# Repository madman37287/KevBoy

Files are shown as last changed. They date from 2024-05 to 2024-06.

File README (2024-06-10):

What is the KevBoy?

In its current state, the KevBoy is a breadboard prototype of a handheld RPI based retro gaming system using the retropie image.
ADD IMAGE

The KevBoy is a 

What is the purpose of making this public git repository?

1. Back-up data.  This project already had to be re-designed from scratch once in the past due to a laptop harddrive failure.  
2. Some SW and HW lack a large number of examples or documentation on the web. I hope this repository and documentation can assist with someone else's learning.
3. Method of showing off the project to any interested parties.

What has already been implemented within the KevBoy?

As previously mentioned, the KevBoy currently has a breadboard prototype shown in the image below.
ADD IMAGE

The breadboard design has 3 visible layers to it.  In the bottom layer, we have the controls.
These controls match what you would expect from a standard controller:
* D-Pad on the far left
* A, B, X, Y buttons on the far right
* Two analog sticks
* select (left) and start (right) buttons in between the analog sticks.

INSERT DIAGRAM

There is also an MCP3008 ADC between the analog sticks that convert the analog voltage outputted from the x and y axis potentiometers into a digital code readable by the PI.

The layer above the controls lives the necessary electrical components needed to connect the controls to the GPIO pins.  
In this layer we have LEDs acting only as Diodes.  These diodes are necessary due to the button matrix solution used to reduce the number of GPIO pins used from 16 to 8.
Without the diodes, multiple button presses can lead to an unpressed button being incorrectly registered (see below)

INSERT DIAGRAM

In its current prototype state, the PI currently has 11 connected buttons (including L3 on the DS3 analog), while the final will support at least 16 when adding R3 and the Triggers.
With several other devices needing to be connected to the GPIO pins, such as ADC, PWM speakers, UPS UART connections, ect, there are simply not enough pins.
The HW/SW solution was to build a button matrix, in which 16 buttons could be supported with 8 pins.

What still needs to be implemented?

* Upgrade to RPI5 (expecting CM5 to release later this year. CM4 to CM5 will not require PCB changes)
* Battery solution for RPI5 (5V 5A max compared to RPI4 5V 3A)
* PCB updates & PCB prototype
* 3D printable model for casing
* digitally controllable potentiometers for volume control
* code to support WIFI and Bluetooth status display. Perhaps also an airplane mode.
* Unit cooling

Setup:

Sound:
https://learn.adafruit.com/adafruit-max98357-i2s-class-d-mono-amp/raspberry-pi-usage

Background music: 
https://github.com/Naprosnia/RetroPie_BGM_Player

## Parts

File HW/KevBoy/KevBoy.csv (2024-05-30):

Source: | C:\Users\kevin\OneDrive\Documents\Kevboy\Kevboy.kicad_sch
Date: | 8/27/2022 11:19:42 AM
Tool: | Eeschema (5.99.0-12724-g8c8d66a181)
Generator: | C:\Program Files\KiCad\5.99\bin\scripting\plugins/bom_csv_grouped_by_value.py
Component Count: | 47
Individual Components:
Item | Qty | Reference(s) | Value | LibPart | Footprint | Datasheet | Description | Height | Manufacturer_Name | Manufacturer_Part_Number | Mouser Part Number | Mouser Price/Stock
 |  | D1 | DIODE | pspice:DIODE | Diode_SMD:D_0805_2012Metric | ~
 |  | D2 | DIODE | pspice:DIODE | Diode_SMD:D_0805_2012Metric | ~
 |  | D3 | DIODE | pspice:DIODE | Diode_SMD:D_0805_2012Metric | ~
 |  | D4 | DIODE | pspice:DIODE | Diode_SMD:D_0805_2012Metric | ~
 |  | D5 | DIODE | pspice:DIODE | Diode_SMD:D_0805_2012Metric | ~
 |  | D6 | DIODE | pspice:DIODE | Diode_SMD:D_0805_2012Metric | ~
 |  | D7 | DIODE | pspice:DIODE | Diode_SMD:D_0805_2012Metric | ~
 |  | D8 | DIODE | pspice:DIODE | Diode_SMD:D_0805_2012Metric | ~
 |  | D9 | DIODE | pspice:DIODE | Diode_SMD:D_0805_2012Metric | ~
 |  | D10 | DIODE | pspice:DIODE | Diode_SMD:D_0805_2012Metric | ~
 |  | D11 | DIODE | pspice:DIODE | Diode_SMD:D_0805_2012Metric | ~
 |  | D12 | DIODE | pspice:DIODE | Diode_SMD:D_0805_2012Metric | ~
 |  | J5 | 208658-1051 | mouser:208658-1051 | 2086581051 | https://www.mouser.com/ProductDetail/Molex/208658-1051?qs=BJlw7L4Cy7%252Bu27sIkZU3Xw%3D%3D | 1.0 HDMI R/A HEADER ASSY (I/M TYPE) | 6.44 | Molex | 208658-1051 | 538-208658-1051 | https://www.mouser.co.uk/ProductDetail/Molex/208658-1051?qs=BJlw7L4Cy7%252Bu27sIkZU3Xw%3D%3D
 |  | J6 | 208658-1051 | mouser:208658-1051 | 2086581051 | https://www.mouser.com/ProductDetail/Molex/208658-1051?qs=BJlw7L4Cy7%252Bu27sIkZU3Xw%3D%3D | 1.0 HDMI R/A HEADER ASSY (I/M TYPE) | 6.44 | Molex | 208658-1051 | 538-208658-1051 | https://www.mouser.co.uk/ProductDetail/Molex/208658-1051?qs=BJlw7L4Cy7%252Bu27sIkZU3Xw%3D%3D
 |  | J7 | 692122030100 | mouser:692122030100 | 692122030100 | https://katalog.we-online.de/em/datasheet/692122030100.pdf | Wurth Elektronik WR-COM Series, Right Angle Through Hole, Version 3.0 Type A USB Connector, Receptacle | 7.55 | Wurth Elektronik | 692122030100 | 710-692122030100 | https://www.mouser.co.uk/ProductDetail/Wurth-Elektronik/692122030100?qs=e5m3IbTHPW%252BwkSEzX%252BzXuw%3D%3D
 |  | J8 | 692122030100 | mouser:692122030100 | 692122030100 | https://katalog.we-online.de/em/datasheet/692122030100.pdf | Wurth Elektronik WR-COM Series, Right Angle Through Hole, Version 3.0 Type A USB Connector, Receptacle | 7.55 | Wurth Elektronik | 692122030100 | 710-692122030100 | https://www.mouser.co.uk/ProductDetail/Wurth-Elektronik/692122030100?qs=e5m3IbTHPW%252BwkSEzX%252BzXuw%3D%3D
 |  | J9 | 692122030100 | mouser:692122030100 | 692122030100 | https://katalog.we-online.de/em/datasheet/692122030100.pdf | Wurth Elektronik WR-COM Series, Right Angle Through Hole, Version 3.0 Type A USB Connector, Receptacle | 7.55 | Wurth Elektronik | 692122030100 | 710-692122030100 | https://www.mouser.co.uk/ProductDetail/Wurth-Elektronik/692122030100?qs=e5m3IbTHPW%252BwkSEzX%252BzXuw%3D%3D
 |  | J10 | 692122030100 | mouser:692122030100 | 692122030100 | https://katalog.we-online.de/em/datasheet/692122030100.pdf | Wurth Elektronik WR-COM Series, Right Angle Through Hole, Version 3.0 Type A USB Connector, Receptacle | 7.55 | Wurth Elektronik | 692122030100 | 710-692122030100 | https://www.mouser.co.uk/ProductDetail/Wurth-Elektronik/692122030100?qs=e5m3IbTHPW%252BwkSEzX%252BzXuw%3D%3D
 |  | J11 | USB4110-GF-A | mouser:USB4110-GF-A | USB4110GFA | https://gct.co/files/drawings/usb4110.pdf | CONN USB 2.0 TYPE-C R/A SMT | 3.26 | GCT (GLOBAL CONNECTOR TECHNOLOGY) | USB4110-GF-A | 640-USB4110-GF-A | https://www.mouser.co.uk/ProductDetail/GCT/USB4110-GF-A?qs=KUoIvG%2F9IlYiZvIXQjyJeA%3D%3D
 |  | J12 | MEM2051-00-195-00-A | mouser:MEM2051-00-195-00-A | MEM20510019500A | https://gct.co/files/drawings/mem2051.pdf | MICRO SD PUSH PUSH, OPEN, SMT, 1 | 2.05 | GCT (GLOBAL CONNECTOR TECHNOLOGY) | MEM2051-00-195-00-A | 640-MEM20510019500A | https://www.mouser.co.uk/ProductDetail/GCT/MEM2051-00-195-00-A?qs=KUoIvG%2F9Ilat7yfJRNWXUQ%3D%3D
 |  | J13 | Conn_01x03 | Connector_Generic:Conn_01x03 | Connector_JST:JST_EH_S3B-EH_1x03_P2.50mm_Horizontal | ~
 |  | J14 | Conn_01x04 | Connector_Generic:Conn_01x04 | Connector_JST:JST_EH_S4B-EH_1x04_P2.50mm_Horizontal | ~
 |  | J15 | Conn_01x04 | Connector_Generic:Conn_01x04 | Connector_JST:JST_EH_S4B-EH_1x04_P2.50mm_Horizontal | ~
 |  | R1 | 470 | Device:R | Resistor_SMD:R_1206_3216Metric | ~
 |  | R2 | 470 | Device:R | Resistor_SMD:R_1206_3216Metric | ~
 |  | R3 | 470 | Device:R | Resistor_SMD:R_1206_3216Metric | ~
 |  | R4 | 470 | Device:R | Resistor_SMD:R_1206_3216Metric | ~
 |  | R5 | 10k | Device:R | Resistor_SMD:R_1206_3216Metric | ~
 |  | R6 | 10k | Device:R | Resistor_SMD:R_1206_3216Metric | ~
 |  | R7 | 10k | Device:R | Resistor_SMD:R_1206_3216Metric | ~
 |  | SW1 | SW_Push | Switch:SW_Push | Button_Switch_THT:SW_PUSH_6mm_H7.3mm | ~
 |  | SW2 | SW_Push | Switch:SW_Push | Button_Switch_THT:SW_PUSH_6mm_H7.3mm | ~
 |  | SW3 | SW_Push | Switch:SW_Push | Button_Switch_THT:SW_PUSH_6mm_H7.3mm | ~
 |  | SW4 | SW_Push | Switch:SW_Push | Button_Switch_THT:SW_PUSH_6mm_H7.3mm | ~
 |  | SW5 | SW_Push | Switch:SW_Push | Button_Switch_THT:SW_PUSH_6mm_H7.3mm | ~
 |  | SW6 | SW_Push | Switch:SW_Push | Button_Switch_THT:SW_PUSH_6mm_H7.3mm | ~
 |  | SW7 | SW_Push | Switch:SW_Push | Button_Switch_THT:SW_PUSH_6mm_H7.3mm | ~
 |  | SW8 | SW_Push | Switch:SW_Push | Button_Switch_THT:SW_PUSH_6mm_H7.3mm | ~
 |  | SW9 | SW_Push | Switch:SW_Push | Button_Switch_THT:SW_PUSH_6mm_H7.3mm | ~
 |  | SW10 | SW_Push | Switch:SW_Push | Button_Switch_THT:SW_PUSH_6mm_H7.3mm | ~
 |  | SW11 | SW_Push | Switch:SW_Push | Button_Switch_THT:SW_PUSH_6mm_H7.3mm | ~
 |  | SW12 | SW_Push | Switch:SW_Push | Button_Switch_THT:SW_PUSH_6mm_H7.3mm | ~
 |  | U1 | Conn_01x40_Male | Connector:Conn_01x40_Male |  | ~
 |  | U2 | MCP3008 | Analog_ADC:MCP3008 | MCP3008:SOIC127P600X175-16N | http://ww1.microchip.com/downloads/en/DeviceDoc/21295d.pdf
 |  | U3 | cm4conn | cm4conn:cm4conn | CM4IO:Raspberry-Pi-4-Compute-Module
 |  | U4 | DS3_Analog | :DS3_Analog_1 | joystick:JOYSTICK
 |  | U5 | DS3_Analog | AnalogStick:DS3_Analog | joystick:JOYSTICK
Collated Components:
Item | Qty | Reference(s) | Value | LibPart | Footprint | Datasheet | Description | Height | Manufacturer_Name | Manufacturer_Part_Number | Mouser Part Number | Mouser Price/Stock
1 | 12 | D1, D2, D3, D4, D5, D6, D7, D8, D9, D10, D11, D12 | DIODE | pspice:DIODE | Diode_SMD:D_0805_2012Metric | ~
2 | 2 | J5, J6 | 208658-1051 | mouser:208658-1051 | 2086581051 | https://www.mouser.com/ProductDetail/Molex/208658-1051?qs=BJlw7L4Cy7%252Bu27sIkZU3Xw%3D%3D | 1.0 HDMI R/A HEADER ASSY (I/M TYPE) | 6.44 | Molex | 208658-1051 | 538-208658-1051 | https://www.mouser.co.uk/ProductDetail/Molex/208658-1051?qs=BJlw7L4Cy7%252Bu27sIkZU3Xw%3D%3D
3 | 4 | J7, J8, J9, J10 | 692122030100 | mouser:692122030100 | 692122030100 | https://katalog.we-online.de/em/datasheet/692122030100.pdf | Wurth Elektronik WR-COM Series, Right Angle Through Hole, Version 3.0 Type A USB Connector, Receptacle | 7.55 | Wurth Elektronik | 692122030100 | 710-692122030100 | https://www.mouser.co.uk/ProductDetail/Wurth-Elektronik/692122030100?qs=e5m3IbTHPW%252BwkSEzX%252BzXuw%3D%3D
4 | 1 | J11 | USB4110-GF-A | mouser:USB4110-GF-A | USB4110GFA | https://gct.co/files/drawings/usb4110.pdf | CONN USB 2.0 TYPE-C R/A SMT | 3.26 | GCT (GLOBAL CONNECTOR TECHNOLOGY) | USB4110-GF-A | 640-USB4110-GF-A | https://www.mouser.co.uk/ProductDetail/GCT/USB4110-GF-A?qs=KUoIvG%2F9IlYiZvIXQjyJeA%3D%3D
5 | 1 | J12 | MEM2051-00-195-00-A | mouser:MEM2051-00-195-00-A | MEM20510019500A | https://gct.co/files/drawings/mem2051.pdf | MICRO SD PUSH PUSH, OPEN, SMT, 1 | 2.05 | GCT (GLOBAL CONNECTOR TECHNOLOGY) | MEM2051-00-195-00-A | 640-MEM20510019500A | https://www.mouser.co.uk/ProductDetail/GCT/MEM2051-00-195-00-A?qs=KUoIvG%2F9Ilat7yfJRNWXUQ%3D%3D
6 | 1 | J13 | Conn_01x03 | Connector_Generic:Conn_01x03 | Connector_JST:JST_EH_S3B-EH_1x03_P2.50mm_Horizontal | ~
7 | 2 | J14, J15 | Conn_01x04 | Connector_Generic:Conn_01x04 | Connector_JST:JST_EH_S4B-EH_1x04_P2.50mm_Horizontal | ~
8 | 4 | R1, R2, R3, R4 | 470 | Device:R | Resistor_SMD:R_1206_3216Metric | ~
9 | 3 | R5, R6, R7 | 10k | Device:R | Resistor_SMD:R_1206_3216Metric | ~
10 | 12 | SW1, SW2, SW3, SW4, SW5, SW6, SW7, SW8, SW9, SW10, SW11, SW12 | SW_Push | Switch:SW_Push | Button_Switch_THT:SW_PUSH_6mm_H7.3mm | ~
11 | 1 | U1 | Conn_01x40_Male | Connector:Conn_01x40_Male |  | ~
12 | 1 | U2 | MCP3008 | Analog_ADC:MCP3008 | MCP3008:SOIC127P600X175-16N | http://ww1.microchip.com/downloads/en/DeviceDoc/21295d.pdf
13 | 1 | U3 | cm4conn | cm4conn:cm4conn | CM4IO:Raspberry-Pi-4-Compute-Module
14 | 1 | U4 | DS3_Analog | :DS3_Analog_1 | joystick:JOYSTICK
15 | 1 | U5 | DS3_Analog | AnalogStick:DS3_Analog | joystick:JOYSTICK

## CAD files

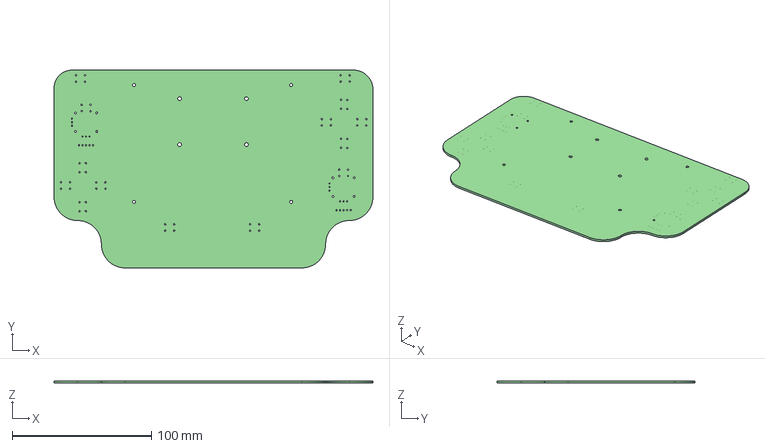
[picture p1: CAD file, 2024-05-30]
HW/KevBoy/KevBoy.step
229.0 x 142.0 x 1.60 mm

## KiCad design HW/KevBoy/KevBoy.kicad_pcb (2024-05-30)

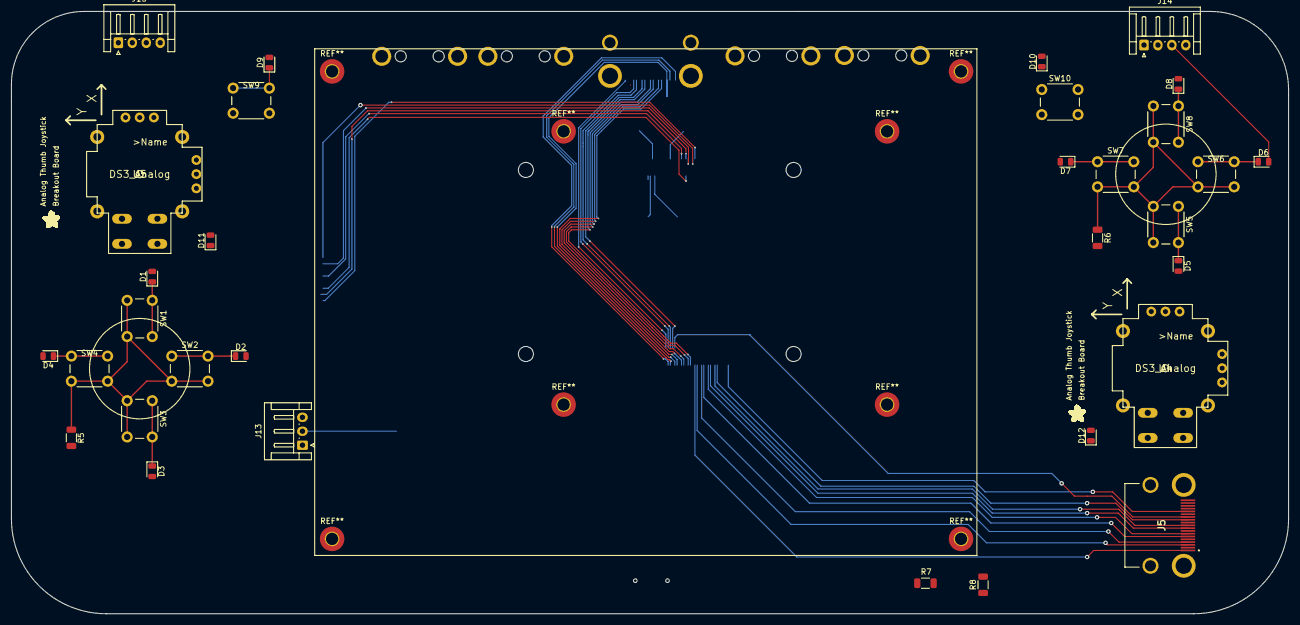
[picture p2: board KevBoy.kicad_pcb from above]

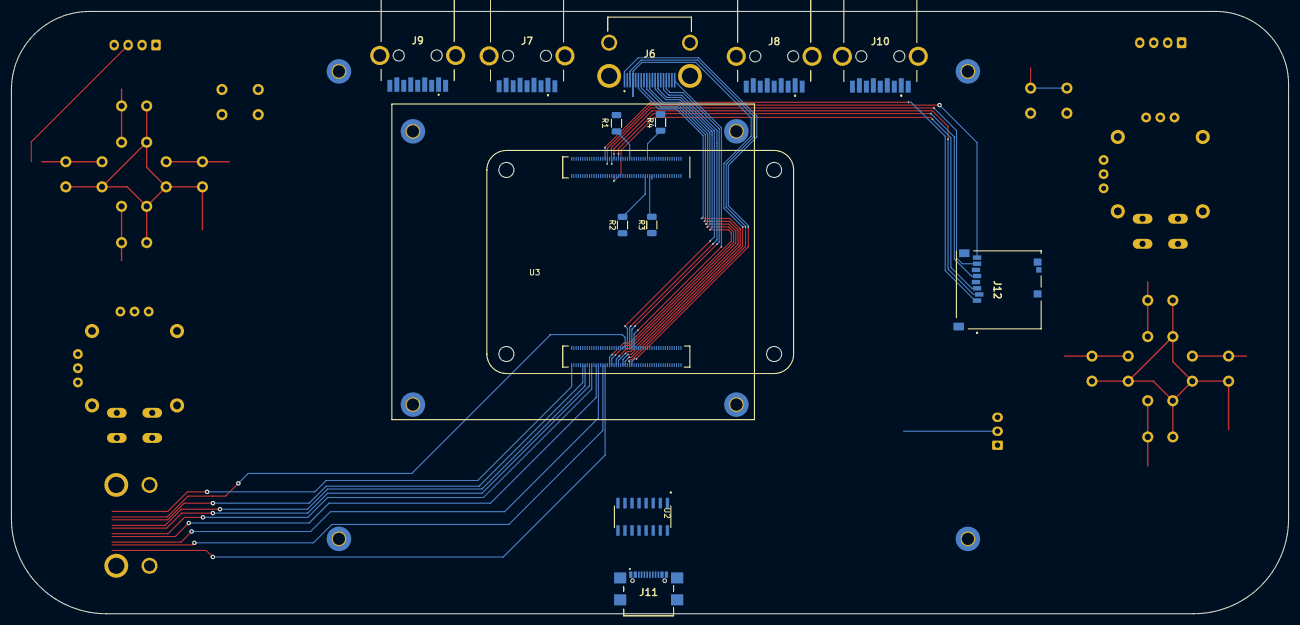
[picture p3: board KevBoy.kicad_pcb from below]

Board: 2 copper layers, 229.0 x 108.0 mm, 47 parts (13 on the bottom side), 58 nets.

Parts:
D1, D2, D3, D4, D5, D6, D7, D8, D9, D10, D11, D12: DIODE; D_0805_2012Metric
J5, J6: 208658-1051; 2086581051
J7, J8, J9, J10: 692122030100
J11: USB4110-GF-A; USB4110GFA
J12: MEM2051-00-195-00-A; MEM20510019500A
J13: Conn_01x03; JST_EH_S3B-EH_1x03_P2.50mm_Horizontal
J14, J15: Conn_01x04; JST_EH_S4B-EH_1x04_P2.50mm_Horizontal
R1, R2, R3, R4: 470; R_1206_3216Metric
R5, R6, R7, R8: 10k; R_1206_3216Metric
SW1, SW2, SW3, SW4, SW5, SW6, SW7, SW8, SW9, SW10: SW_Push; SW_PUSH_6mm_H7.3mm
U2: MCP3008; SOIC127P600X175-16N
U3: cm4conn; Raspberry-Pi-4-Compute-Module
U4, U5: DS3_Analog; JOYSTICK
U$1, U$1#2: ADAFRUIT200MIL

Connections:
5V: J13.1, U3.77, U3.79, U3.81, U3.83, U3.85, U3.87
ChargerInput: J11.A4, J11.A9, J11.B4, J11.B9
GND: J11.A1, J11.A12, J11.B1, J11.B12, J12.P6 (VSS), J13.3, R5.2, R6.2, R7.2, R8.2, U2.9 (DGND), U2.14 (AGND), U3.1, U3.2, U3.7, U3.8, U3.13, U3.14, U3.22, U3.23, U3.32, U3.33, U3.42, U3.43, U3.52, U3.53, U3.59, U3.60, U3.65, U3.66, U3.71, U3.74, U3.98, U3.107, U3.108, U3.113, U3.114, U3.119, U3.120, U3.125, U3.126, U3.131, U3.132, U3.137, U3.138, U3.144, U3.150, U3.155, U3.156, U3.161, U3.162, U3.167, U3.168, U3.173, U3.174, U3.179, U3.180, U3.185, U3.186, U3.191, U3.192, U3.197, U3.198
unnamed: D1.1 (K), SW1.1
unnamed: D1.2 (A), D5.2 (A), D9.2 (A), J14.2, R1.1
unnamed: D2.1 (K), SW2.1
unnamed: D3.1 (K), SW3.1
unnamed: D4.1 (K), SW4.1
unnamed: D5.1 (K), SW5.1
unnamed: D6.1 (K), SW6.1
unnamed: D7.1 (K), SW7.1
unnamed: D8.1 (K), SW8.1
unnamed: D9.1 (K), SW9.1
unnamed: D10.1 (K), SW10.1
unnamed: D2.2 (A), D6.2 (A), D10.2 (A), J14.3, R2.1
unnamed: D3.2 (A), D7.2 (A), D11.2 (A), J15.2, R3.1
unnamed: D4.2 (A), D8.2 (A), D12.2 (A), J15.3, R4.1
unnamed: J5.1, U3.170
unnamed: J5.3, U3.172
unnamed: J5.4, U3.176
unnamed: J5.6, U3.178
unnamed: J5.7, U3.182
unnamed: J5.9, U3.184
unnamed: J5.10, U3.188
unnamed: J5.12, U3.190
unnamed: J5.13, U3.151
unnamed: J5.15, U3.200
unnamed: J5.16, U3.199
unnamed: J5.19, U3.153
unnamed: J6.1, U3.146
unnamed: J6.3, U3.148
unnamed: J6.4, U3.152
unnamed: J6.6, U3.154
unnamed: J6.7, U3.158
unnamed: J6.9, U3.160
unnamed: J6.10, U3.164
unnamed: J6.12, U3.166
unnamed: J6.13, U3.149
unnamed: J6.15, U3.147
unnamed: J6.16, U3.145
unnamed: J6.19, U3.143
unnamed: J12.P1 (DAT2), U3.69
unnamed: J12.P2 (CD/DAT3), U3.61
unnamed: J12.P3 (CMD), U3.62
unnamed: J12.P5 (CLK), U3.57
unnamed: J12.P7 (DAT0), U3.63
unnamed: J12.P8 (DAT1), U3.67
unnamed: J13.2, U3.28
unnamed: J14.4, J15.1
unnamed: J15.4, R8.1
unnamed: R1.2, U3.47
unnamed: R2.2, U3.34
unnamed: R3.2, U3.30
unnamed: R4.2, U3.31
unnamed: R5.1, SW1.2, SW2.2, SW3.2, SW4.2, U3.50
unnamed: R6.1, SW5.2, SW6.2, SW7.2, SW8.2, U3.48
unnamed: R7.1, SW9.2, SW10.2, U3.46
unnamed: U2.15 (Vref), U2.16 (Vdd)

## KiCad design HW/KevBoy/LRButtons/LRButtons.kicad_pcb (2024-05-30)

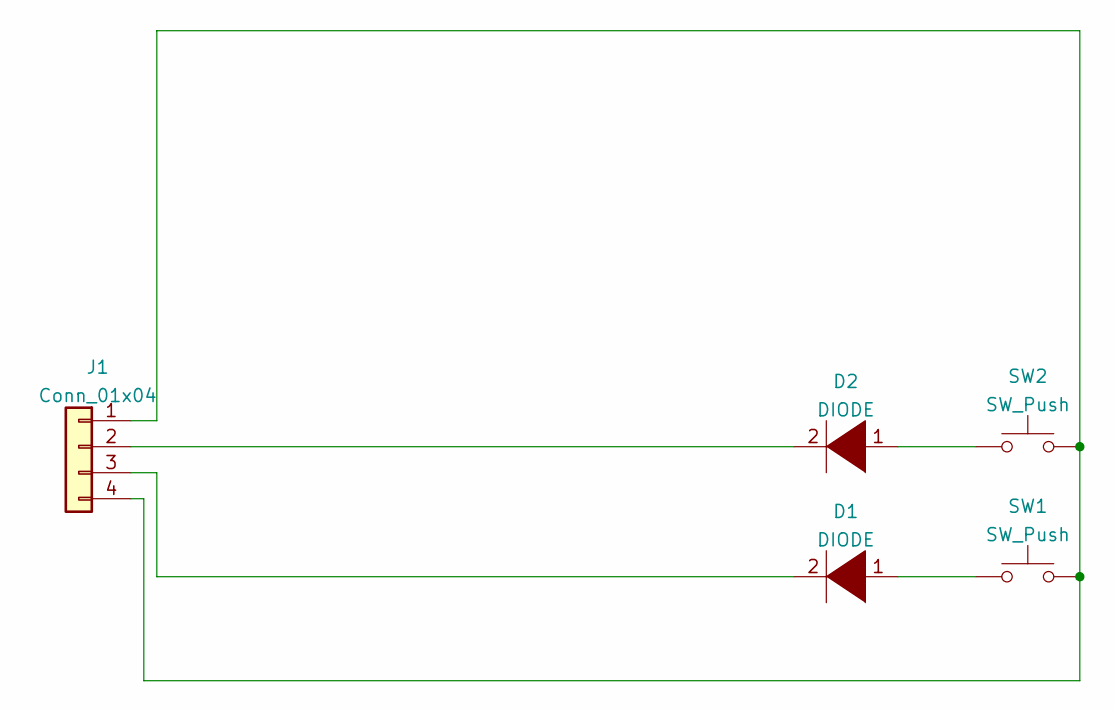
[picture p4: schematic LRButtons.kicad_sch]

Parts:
D1, D2: DIODE; D_0805_2012Metric
J1: Conn_01x04; JST_EH_B4B-EH-A_1x04_P2.50mm_Vertical
SW1, SW2: SW_Push; SW_PUSH_6mm_H7.3mm

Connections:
unnamed: D1.2 (A), J1.3
unnamed: D2.2 (A), J1.2
unnamed: J1.1, J1.4, SW1.2, SW2.2
unnamed: D1.1 (K), SW1.1
unnamed: D2.1 (K), SW2.1

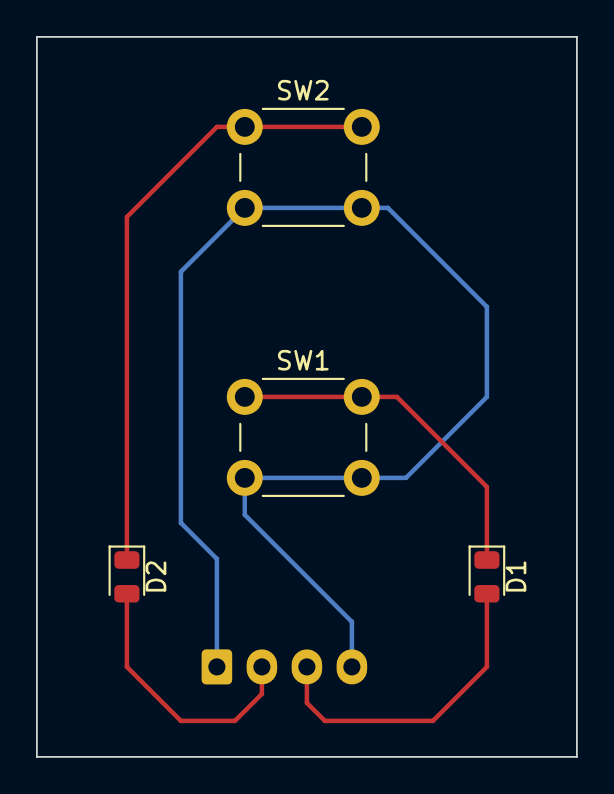
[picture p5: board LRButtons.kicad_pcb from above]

Board: 2 copper layers, 30.0 x 40.0 mm, 5 parts (1 on the bottom side), 5 nets.

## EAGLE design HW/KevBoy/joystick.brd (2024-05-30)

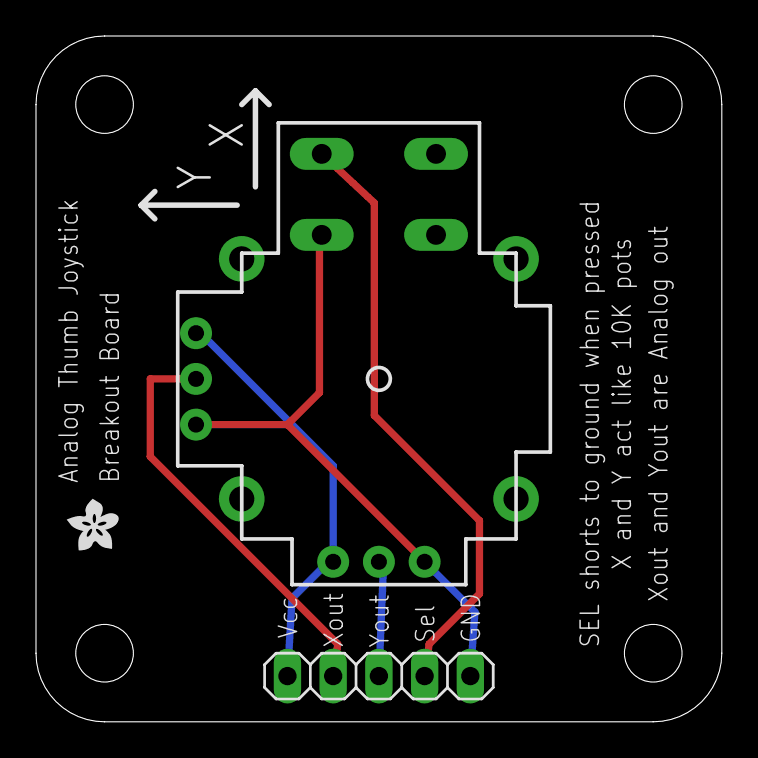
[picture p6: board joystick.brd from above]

Board: 2 copper layers, 38.1 x 38.1 mm, 3 parts (0 on the bottom side), 5 nets.

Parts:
JP1: 1X05
U1: JOYSTICKPTH; JOYSTICK
U$1: ADAFRUIT200MIL

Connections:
unnamed: JP1.5, U1.H1, U1.V1
unnamed: JP1.1, U1.B2A, U1.H3, U1.V3
unnamed: JP1.4, U1.V2
unnamed: JP1.3, U1.H2
unnamed: JP1.2, U1.B1A

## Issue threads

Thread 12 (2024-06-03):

RPi UPSPack max current investigation

madman37287, 2024-06-03:
The documentation refers to 3A max output current.  However, it is unclear if this is a constraint of the board or of the batteries themselves.  Because two LIPO batteries are being investigated anyways, two of these boards can be connected in parallel in theory, with diodes preventing reversed current.  the obvious downside is that this will double the cost of the battery solution from 33 to 66 per build.  Plus will be double battery life and potentially allow for USB support.

USBA 2.0 uses max of .5A, which means max current draw from the usb ports is 2A.  With RPi 5 potentially drawing a max of 5A, this could put us an amp over max current. More investigation necessary.

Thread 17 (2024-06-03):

Status button implementation

madman37287, 2024-06-03:
all status displays should be toggleable with a button or event.  A button will be placed on the bottom or back of the board with the express purpose of toggling the status bar.  This way, battery, wifi, ect can be checked at any given moment without fear of covering crucial parts of the screen.

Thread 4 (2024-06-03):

Replace current MicroSD card reader with the one currently being used by RPI's CM dev board

madman37287, 2024-06-03:
Although current SD Card reader should be sufficient, for the purpose of this project I want to use one that is already proven to work by RPi manufacturers.

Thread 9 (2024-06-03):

Build PCB Prototype

madman37287, 2024-06-03:
The easiest way to do this will be to use solder paste and stencil.  It is rumored that modern easy bake ovens get hot enough to flow solder paste and may be a viable option.  Heat gun may also be viable.

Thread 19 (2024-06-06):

RPi5 Compatibility: Switch to I2S audio

madman37287, 2024-06-06:
PWM audio is no longer supported on the pi5.  as such, the audio output should be switched to the I2S protocol.

madman37287, 2024-06-06:
For the time being, bluetooth speaker can be used for testing as a workaround

madman37287, 2024-06-10:
complete with instructions from: https://learn.adafruit.com/adafruit-max98357-i2s-class-d-mono-amp/raspberry-pi-usage

Closed 2024-06-10.

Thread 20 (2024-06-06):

RPi 5 Compatibility: Ensure ButtonLogic5.py script works on the RPi 4 for cross compatibility

madman37287, 2024-06-06:
Button logic script had to be altered due to a change in the GPIO interface in the RPi5.  However, because gpiozero is compatible with all raspberry pi models, it should be cross compatible as well.  Cross compatibility is important because the first PCB model will be built with a CM4 due to the CM5 not existing yet.

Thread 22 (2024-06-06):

RPi 5 Compatibility: Use Multimeter to capture max current thresholds.

madman37287, 2024-06-06:
A backup battery solution has been created in the event I need more current.  Investigate if it is needed.

madman37287, 2024-06-10:
seems to be around 2A.  need to experiment more

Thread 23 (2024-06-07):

Add R1/L1/R2/L2 buttons to prototype

madman37287, 2024-06-07:
Going to be testing some gamecube games, which will require at minimum R1, R2, and L2.  Might as well add all 4 for testing purposes.

madman37287, 2024-06-07:
L and R buttons added and wired

Closed 2024-06-07.

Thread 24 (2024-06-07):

RPi 5 Compatibility: Background music

madman37287, 2024-06-07:
On the Pi 4, I was forced to abandoned custom background music due to some weird issues with the PWM speakers.  Now that this will not be an issue, bring back custom background music for KevBoy's main menu.

madman37287, 2024-06-10:
redownloaded BGM-player 2.0.  Still compatible with PI 5

Closed 2024-06-10.

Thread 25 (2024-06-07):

RPi 5 Specific issue: Implement Dolphin Exit Shortcut

madman37287, 2024-06-07:
Dolphin is currently an experimental package within retroarch, probably due to the fact that it likely is not easily externally controllable.  Because of this, certain things need to be set manually in a one-time setup fashion, such as the controls.  Supposedly there is a file somewhere that can be edited with a combination of buttons to back out of the emulation back to retroarch.  This should be configured.

madman37287, 2024-06-07:
Start+Sel closes dolphin, editable in gui hotkeys option

Closed 2024-06-07.

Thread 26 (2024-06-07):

RPi 5 Specific Issue: Sync Dolphin controls to retroarch

madman37287, 2024-06-07:
Because dolphin is an experimental package, retroarch controls do not natively tie to the dolphin emulator, resulting in some manual workarounds to set controls.  I am pretty sure that dolphin stores controller setup in a random config file somewhere, to which I would imagine that Retroarch does the same.  In theory, it should be possible to create an event that updates Dolphin's config whenever retroarch's config updates.

madman37287, 2024-06-07:
To change controls currently, a mouse device needs to be connected.  Although this is fine for debugging, this is not a viable solution in the long run

madman37287, 2024-06-07:
Now that I have thought about it for a second more, this does not even have to sync on retroarch config update.  This could sync on game launch.

madman37287, 2024-06-07:
controls live in /opt/retropie/configs/gc/Config/

madman37287, 2024-06-07:
specific file is GCPadNew.ini

madman37287, 2024-06-07:
pulling out our old friend, "/opt/retropie/configs/gc/emulators.cfg", you can actually populate a new field with a command.  I believe it would be an almost trivial task to create a python script which syncs the controllers and then starts the game.

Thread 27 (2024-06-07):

RPi 5 Specific Issue: Get Pi 5 off the wall

madman37287, 2024-06-07:
Pi5 current draw is currently an unknown.  once it is a known, determine the battery solution to get pi off wall power

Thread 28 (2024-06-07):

RPi 5 Specific Issue: Bluetooth investigation

madman37287, 2024-06-07:
Bluetooth speaker fails to connect.  Online resources seem to think this is specific to bluetooth audio, which will not be an issue after the I2S.  Ensure that the bluetooth connectivity issues does not occur with other devices.  If it does, then fix the issue.

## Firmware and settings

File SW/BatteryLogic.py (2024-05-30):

##############################################################
# Author: Kevin Brandt                                       #
##############################################################

import serial
import math
import re
from time import sleep
import subprocess

class BatteryLogic():
    def __init__(self):
        self.chargeIcon = "/home/pi/RetroPie/roms/images/chargeBat.png"
        self.batIcon    = "/home/pi/RetroPie/roms/images/bat"
        self.currIcon   = self.batIcon + '100.png'
        self.number     = "/home/pi/RetroPie/roms/images/number"
        self.percent    = "/home/pi/RetroPie/roms/images/percent.png"
        self.currCap    = 0

        self.pngview_path = "/home/pi/src/raspidmx/pngview/pngview"
        self.pngview_call = [self.pngview_path, "-d", "0", "-b", "0x0000", "-n", "-l", "15000", "-y", "0", "-x"]
        self.resolution = 800
        self.iconSize = 32
        self.position = 3

        self.iconProcess = subprocess.Popen(self.pngview_call + [str(int(self.resolution) - self.iconSize * self.position), self.currIcon])
        self.percentProc = subprocess.Popen(self.pngview_call + [str(int(self.resolution) - 15 * 4), self.percent])
        self.percentProcs = [None, None, None]
        return
    
    def parseData(self, data):
        outData = dict()
        outData['charge'] = ''
        outData['cap'] = ''

        charge = re.findall(r',Vin (.*?),', data)
        cap    = re.findall(r',BATCAP (.*?),', data)
        try:
            print(f'charger = {charge[0]}, cap = {cap[0]}')            
            outData['charge'] = charge[0]
            outData['cap'] = cap[0]
        except Exception as e:
            print(e)
        return outData
    
    def updatePercent(self, cap):
        status = True
        try:
            if self.currCap != cap:
                self.currCap = cap
                count = 0
                strcap = str(cap)
                for i in range(len(self.percentProcs)):
                    if self.percentProcs[i] != None:
                        self.percentProcs[i].kill()
                for i in strcap:
                    self.percentProcs[count] = subprocess.Popen(self.pngview_call + [str(int(self.resolution) - 15 * (3 - count)), self.number + f'{i}.png'])
                    count = count + 1
        except Exception as e:
            print(e)
            status = False
        return status
    
    def changeIcon(self, type):
        if self.currIcon != type:
            self.currIcon = type
            self.iconProcess.kill()
            self.iconProcess = subprocess.Popen(self.pngview_call + [str(int(self.resolution) - self.iconSize * self.position), self.currIcon])
        return

    def main(self):
        failCount = 0
        chargerCon = False
        
        # Connect to the Raspberry pi serial port.  
        # TODO: run a check between S0 and AMA0
        ser = serial.Serial("/dev/ttyS0", 9600, timeout=1)
        
        while True:
            # receive entire message
            received_data = ser.read(100)
            sleep(0.03)
        
            # convert to string
            data = received_data.decode("utf-8")
            print(data, end="")

            outdata = self.parseData(data)

            self.updatePercent(outdata['cap'])

            # check charger status
            if outdata['charge'] == 'GOOD':
                failCount = 0
                chargerCon = True
                self.changeIcon(self.chargeIcon)
                print("charger: connected")
            elif outdata['charge'] == 'NG':
                failCount = 0
                chargerCon = False
                
                self.changeIcon(self.batIcon + f"{math.ceil(int(outdata['cap'])/10) * 10}.png")
                print("charger: disconnected")
            else:
                failCount = failCount + 1
                # A single serial failure happens every few seconds due to split data
                if failCount >= 10:
                    psFailure = True
                    chargerCon = False
                    print("Something went wrong")
    
if __name__ == "__main__":
    batLogic = BatteryLogic()
    batLogic.main()

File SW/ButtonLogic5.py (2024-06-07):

##############################################################
# Author: Kevin Brandt                                       #
##############################################################
# Note: use command 'sudo crontab -e' to open a text file    #
#       In that text file, add the line:                     #
#       @reboot sudo python3 /home/pi/ButtonLogic5.py        #
#       This line will make it so the script starts at boot  #
##############################################################


import sys
import time
# gpiozero compatible on both rpi4 & 5
from gpiozero import LED, Button, MCP3008

try:
    from evdev import uinput, UInput, AbsInfo, ecodes as e
except ImportError:
    exit("This library requires the evdev module\nInstall with: sudo pip install evdev")

# Constants
CENTER_TOLERANCE = 100 # 10 percent deadzone
BUTTON_ERROR_RESOLUTION = 3 # TODO: this should calculate automatically based on latency and complimented with debounce

# button flag initializations
dUp          = 0
dLeft        = 0
dRight       = 0
dDown        = 0
buttonA      = 0
buttonB      = 0
buttonX      = 0
buttonY      = 0
buttonL3     = 0
buttonR3     = 0
buttonSel    = 0
buttonStart  = 0
buttonL1     = 0
buttonL2     = 0
buttonR1     = 0
buttonR2     = 0
leftAnalogX  = 0
leftAnalogY  = 0
rightAnalogX = 0
rightAnalogY = 0

# Error resolution parameter initialization
dUpCnt         = 0
dLeftCnt       = 0
dRightCnt      = 0
dDownCnt       = 0
buttonACnt     = 0
buttonBCnt     = 0
buttonXCnt     = 0
buttonYCnt     = 0
buttonL3Cnt    = 0
buttonR3Cnt    = 0
buttonSelCnt   = 0
buttonStartCnt = 0
buttonL1Cnt    = 0
buttonL2Cnt    = 0
buttonR1Cnt    = 0
buttonR2Cnt    = 0

# initializing controller events
capabilities = {e.EV_SYN: [], 
                e.EV_KEY: [e.BTN_A,       # A/east Button (switch inspired design)
                           e.BTN_B,       # B/south Button (switch inspired design)
                           e.BTN_X,       # X/north Button (switch inspired design)
                           e.BTN_Y,       # Y/west Button (switch inspired design)
                           e.BTN_TOP,     # D-PAD up
                           e.BTN_TOP2,    # D-PAD left
                           e.BTN_PINKIE,  # D-PAD right
                           e.BTN_BASE,    # D-PAD down
                           e.BTN_SELECT,  # Select button
                           e.BTN_START,   # Start Button
                           e.BTN_THUMBL,  # L3 Button
                           e.BTN_THUMBR,  # R3 Button
                           e.BTN_TL,      # L1 Button
                           e.BTN_TL2,     # L2 Button
                           e.BTN_TR,      # R1 Button
                           e.BTN_TR2],    # R2 Button
                e.EV_ABS: [(e.ABS_X, AbsInfo(0, -1000, 1000, 0, 0, 0)),  # Left analog stick X-axis
                           (e.ABS_Y, AbsInfo(0, -1000, 1000, 0, 0, 0)),  # Left analog stick Y-axis
                           (e.ABS_RX, AbsInfo(0, -1000, 1000, 0, 0, 0)), # Right analog stick X-axis
                           (e.ABS_RY, AbsInfo(0, -1000, 1000, 0, 0, 0))] # Right analog stick Y-axis
                           }
    
# setup up the virtual controller (root access required)
try:
    ui = UInput(name="KevBoy Contoller", events=capabilities)
except uinput.UInputError as e:
    sys.stdout.write(e.message)
    sys.stdout.write("Have you tried running as root? sudo {}".format(sys.argv[0]))
    sys.exit(1)

# TODO: implement a bounce time
# initialize input and output pins (Button = input, LED = output)
GPIO23 = Button(23, pull_up=False)
GPIO5  = Button(5,  pull_up=False)
GPIO6  = Button(6,  pull_up=False)
GPIO24 = Button(24, pull_up=False)

GPIO17 = LED(17)
GPIO27 = LED(27)
GPIO22 = LED(22)
GPIO4  = LED(4)

# Set up ADC channels
chan1 = MCP3008(channel=0)
chan2 = MCP3008(channel=1)
chan3 = MCP3008(channel=2)
chan4 = MCP3008(channel=3)

try:
    # TODO: Tie printouts to a verbose flag
    #print("_____________________________________________________________________________________________________________________________")
    #print("| dUp | Lft | right | dwn | A | B | X | Y | Sel | Start | L1 | L2 | R1 | R2 | Left AnalogY | Left AnalogX | RightAnalogY | RightAnalogX |")
    #print("-----------------------------------------------------------------------------------------------------------------------------")
    counter = 0
    startTime = time.time()
    while(1):
        # Calculate the latency of the pushbuttons
        # Because reading time costs a large amount of time, this is reduced by only reading once every 10000 cycles
        if counter == 10000:
            latency = (time.time()-startTime)/counter
            startTime = time.time()
            #print(f'latency = {latency} sec | frequency = {1/latency} Hz')
            # TODO: tie button error resolution to the latency
            #btnErrTime = 0.0005
            #btnErrResolution = int(btnErrTime/latency)
            counter = 0
        counter = counter + 1

        # This could easily be for-looped, but chose not to for ease of readability and adding new buttons
        # each output is activated once at a time.  While an output rail is active, each input rail checks for voltage.
        # a high voltage read during a time period where a given rail is active means a specific button has been pushed.
        #############################################
        # D-PAD Buttons
        #############################################
        GPIO17.on()
        if GPIO23.is_pressed:
            dUp = 1
            dUpCnt = 0
        elif dUpCnt >= BUTTON_ERROR_RESOLUTION:
            dUp = 0
        else:
            dUpCnt += 1

        if GPIO5.is_pressed:
            dLeft = 1
            dLeftCnt = 0
        elif dLeftCnt >= BUTTON_ERROR_RESOLUTION:
            dLeft = 0
        else:
            dLeftCnt += 1

        if GPIO6.is_pressed:
            dRight = 1
            dRightCnt = 0
        elif dRightCnt >= BUTTON_ERROR_RESOLUTION:
            dRight = 0
        else:
            dRightCnt += 1

        if GPIO24.is_pressed:
            dDown = 1
            dDownCnt = 0
        elif dDownCnt >= BUTTON_ERROR_RESOLUTION:
            dDown = 0
        else:
            dDownCnt += 1

        GPIO17.off()
        #############################################
        
        #############################################
        # ABXY Buttons
        #############################################
        GPIO27.on()
        if GPIO23.is_pressed:
            buttonA = 1
            buttonACnt = 0
        elif buttonACnt >= BUTTON_ERROR_RESOLUTION:
            buttonA = 0
        else:
            buttonACnt += 1

        if GPIO5.is_pressed:
            buttonB = 1
            buttonBCnt = 0
        elif buttonBCnt >= BUTTON_ERROR_RESOLUTION:
            buttonB = 0
        else:
            buttonBCnt += 1
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

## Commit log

2024-05-30 initial file push
    [KevBoy.csv, KevBoy.kicad_pcb, KevBoy.kicad_sch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]
2024-06-07 code to support l and r buttons
